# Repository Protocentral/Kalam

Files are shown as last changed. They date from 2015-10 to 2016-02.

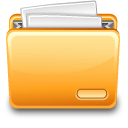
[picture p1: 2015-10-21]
Firmware/nodemcu-flasher-master/Resources/Images/File.png

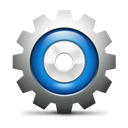
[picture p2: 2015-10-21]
Firmware/nodemcu-flasher-master/Resources/Images/Setting.png

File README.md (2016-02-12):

ProtoCentral Kalam IoT
======================
 [Kalam IoT  
 *ProtoCentral Kalam IoT (PC-4356)*](https://www.protocentral.com/iot/935-kalam-out-of-box-iot.html?search_query=kalam&results=1)

 Internet of Things or IOT is the new hot chic in the market. People seek to connect everything, from their pets to their garage doors to the Internet. The power of connected devices helps one to control it from anywhere in the world. On the other hand, Makers out there are seeking a platform that is easier to use, less cumbersome and more importantly easy on their pockets. With so many platforms out there based on the popular ESP8266, an extremely low cost WiFi module, it is indeed getting difficult for one to choose the right platform. Most commercially available modules are in the form of breakout boards. These require you to work with the limited I/O pins and more importantly will require an additional Arduino board or flashing the ESP8266 core. This can make life miserable for most makers. 

 To make it easier for developers and users alike we made a new genre of IoT platform called the OOB IoT (Out of the Box IoT)! Kalam V1 is an OOB IoT platform. It is an easy to use Arduino based platform that has an integrated ESP8266 module. Just open the box and get started on your projects without having to configure a breakout borad to work with an Arduino! 
This tiny inexpensive hulk of an IoT module in its first avatar (Kalam V1) comes as a single board with power support through USB or an external source through the RAW pin. In the second version we will introduce support for battery packs (and include a couple of battery packs) that can make your life easier as a developer/maker.

 We love our scientists and to commemorate one of the greatest scientists who also served as the most ebullient presidents of India, we aptly named our product Kalam after the late Dr. A.P.J Abdul Kalam. He chose to show the path to millions of students in India and abroad. Kindled their imaginations with his oratory skills and his writings. On occasion of his birthday we present this great platform, we hope will give the IoT space the necessary fillip. 
Inline with Make in India initiatives this is one of our first products of many we will develop, that will help makers and creators across the world!

Features Overload!
-------------------
*	Slide switch - Serial communication support to work on ESP or Atmega328 module individually
*	Firmware upgrade for ESP through USB
*	On board FTDI
*	Onboard regulator 3.3v with 800mA (with a max input of 6V)
*	Can be powered on/off using USB or external supply 
*	Board is pre-flashed  with an AT command set firmware and the same can be used to control ESP8266 module
*	Extra ESP8266 pins broken out for any additional usage requirements
*	802.11 b/g/n
*	Wi-Fi Direct (P2P), soft-AP
*	Integrated TCP/IP protocol stack

Includes:
----------
* Kalam with headers
* Micro USB type-B cable 

Repository Contents
-------------------
* **/Firmware**  - Firmware and bin files for ESP8266
* **/Libraries** - Arduino library and example sketches.
* **/Hardware**  - All Eagle design files (.brd, .sch)

License Information
-------------------
This product is open source!

Please use, reuse, and modify these files as you see fit. Please maintain attribution to Protocentral and release anything derivative under the same license.

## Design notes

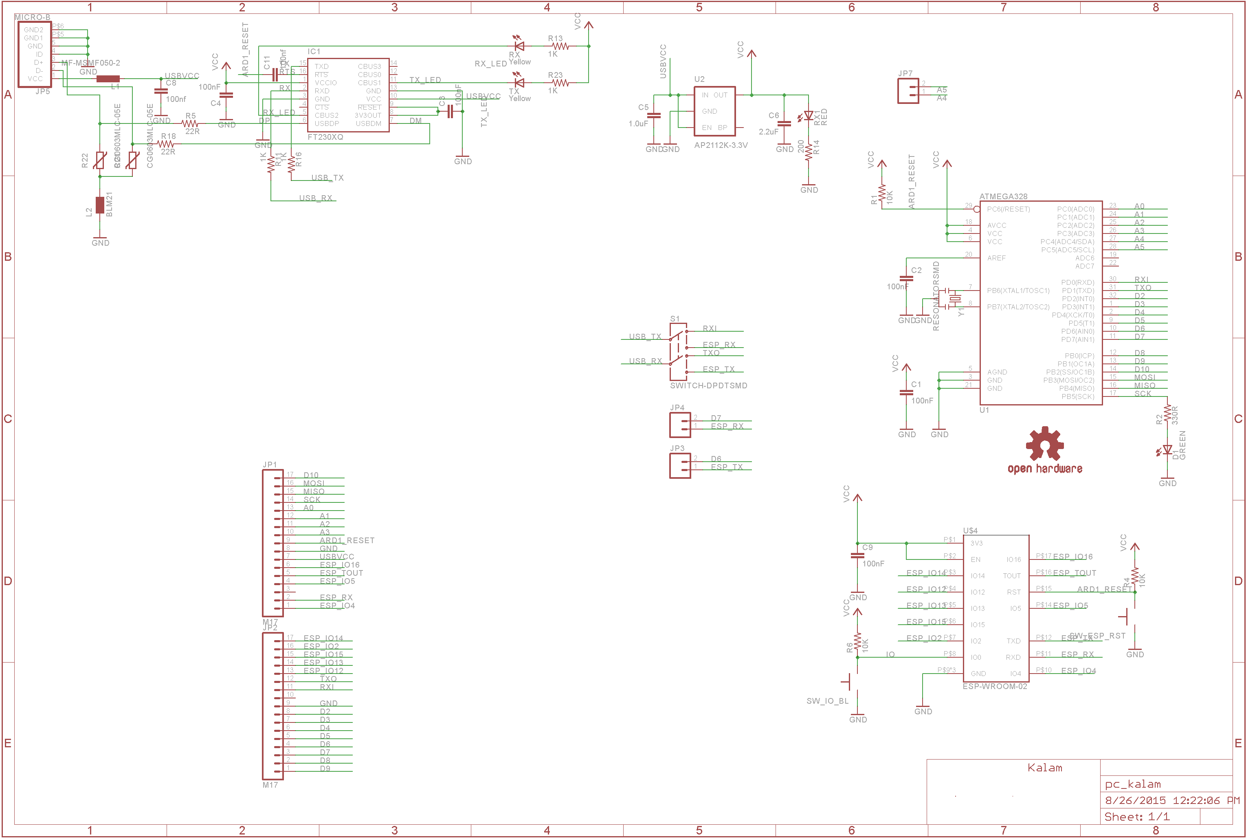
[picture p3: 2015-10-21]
Hardware/Kalam/Kalam.png

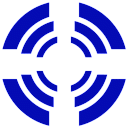
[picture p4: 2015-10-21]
Firmware/nodemcu-flasher-master/Resources/Images/Wait.GIF

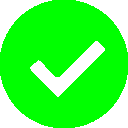
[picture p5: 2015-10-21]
Firmware/nodemcu-flasher-master/Resources/Images/Yes.png

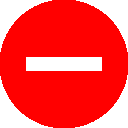
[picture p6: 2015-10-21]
Firmware/nodemcu-flasher-master/Resources/Images/No.png

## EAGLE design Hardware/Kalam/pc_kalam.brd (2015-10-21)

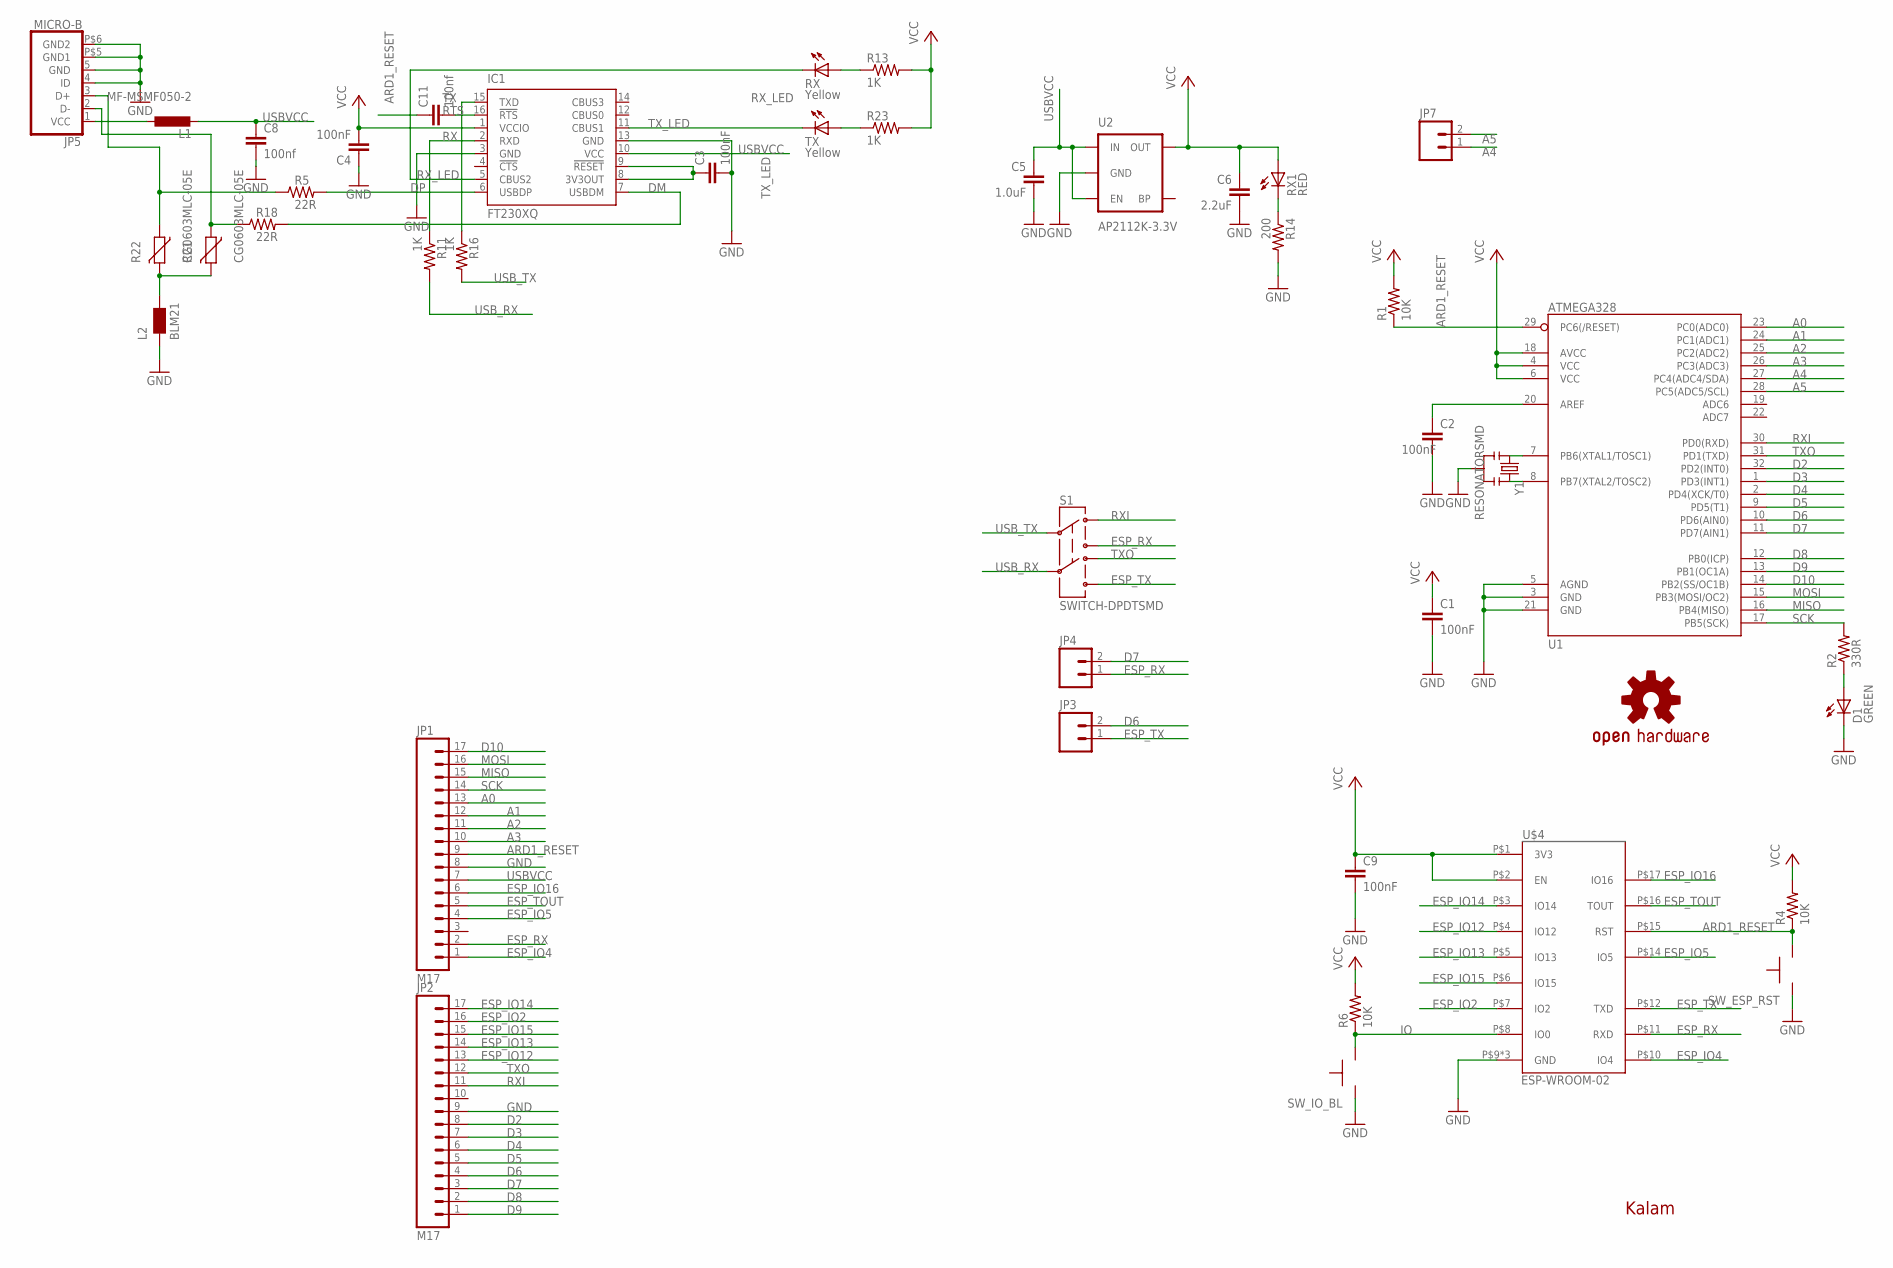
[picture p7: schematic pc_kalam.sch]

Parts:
C1, C2, C9: 100nF; C0402
C3, C4: 100nF; C0805
C5: 1.0uF; 0805
C6: 2.2uF; C0805
C8, C11: 100nf; C0805
D1: GREEN; LED-0603
IC1: FT230XQ; QFN16
JP1, JP2: M17; 1X17
JP3, JP4, JP7: M02PTH; 1X02
JP5: MICRO-B
L1: MF-MSMF050-2; L1812
L2: BLM21; 0805
R1, R4, R6: 10K; R0402
R2: 330R; R0402
R5, R18: 22R; R0805
R11, R13, R16, R23: 1K; R0805
R14: 200; R0805
R21, R22: CG0603MLC-05E; CT/CN0603
RX: Yellow; CHIPLED_0603
RX1: RED; CHIPLED_0603
S1: SWITCH-DPDTSMD; AYZ0202
SW_ESP_RST: B3U-1000P
SW_IO_BL: B3U-1000P
TX: Yellow; CHIPLED_0603
U1: ATMEGA328; TQFP32-08
U2: AP2112K-3.3V; SOT23-5
U$1: OSHW-LOGOS; OSHW-LOGO-S
U$2, U$3: PROTY-LOGO; LOGO-PROTY
U$4: ESP-WROOM-02
U$5: KALAM
Y1: RESONATORSMD; RESONATOR-SMD

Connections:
A0: JP1.13, U1.23 (PC0(ADC0))
A1: JP1.12, U1.24 (PC1(ADC1))
A2: JP1.11, U1.25 (PC2(ADC2))
A3: JP1.10, U1.26 (PC3(ADC3))
A4: JP7.1, U1.27 (PC4(ADC4/SDA))
A5: JP7.2, U1.28 (PC5(ADC5/SCL))
ARD1_RESET: C11.1, JP1.9, R1.1, R4.1, SW_ESP_RST.P$2, U1.29 (PC6(/RESET)), U$4.P$15 (RST)
D2: JP2.8, U1.32 (PD2(INT0))
D3: JP2.7, U1.1 (PD3(INT1))
D4: JP2.6, U1.2 (PD4(XCK/T0))
D5: JP2.5, U1.9 (PD5(T1))
D6: JP2.4, JP3.2, U1.10 (PD6(AIN0))
D7: JP2.3, JP4.2, U1.11 (PD7(AIN1))
D8: JP2.2, U1.12 (PB0(ICP))
D9: JP2.1, U1.13 (PB1(OC1A))
D10: JP1.17, U1.14 (PB2(SS/OC1B))
DM: IC1.7 (USBDM), R18.2
DP: IC1.6 (USBDP), R5.2
ESP_IO2: JP2.16, U$4.P$7 (IO2)
ESP_IO4: JP1.1, U$4.P$10 (IO4)
ESP_IO5: JP1.4, U$4.P$14 (IO5)
ESP_IO12: JP2.13, U$4.P$4 (IO12)
ESP_IO13: JP2.14, U$4.P$5 (IO13)
ESP_IO14: JP2.17, U$4.P$3 (IO14)
ESP_IO15: JP2.15, U$4.P$6 (IO15)
ESP_IO16: JP1.6, U$4.P$17 (IO16)
ESP_RX: JP1.2, JP4.1, S1.3, U$4.P$11 (RXD)
ESP_TOUT: JP1.5, U$4.P$16 (TOUT)
ESP_TX: JP3.1, S1.6, U$4.P$12 (TXD)
GND: C1.2, C2.2, C3.2, C4.1, C5.2, C6.2, C8.2, C9.2, D1.C, IC1.3 (GND), IC1.13 (GND), JP1.8, JP2.9, JP5.4 (ID), JP5.5 (GND), JP5.P$5 (GND1), JP5.P$6 (GND2), L2.1, R14.2, SW_ESP_RST.P$1, SW_IO_BL.P$1, U1.3 (GND), U1.5 (AGND), U1.21 (GND), U2.2 (GND), U$4.P$9 (GND), U$4.P$13 (GND), U$4.P$18 (GND), Y1.2
IO: R6.1, SW_IO_BL.P$2, U$4.P$8 (IO0)
MISO: JP1.15, U1.16 (PB4(MISO))
MOSI: JP1.16, U1.15 (PB3(MOSI/OC2))
unnamed: C2.1, U1.20 (AREF)
unnamed: U1.8 (PB7(XTAL2/TOSC2)), Y1.3
unnamed: U1.7 (PB6(XTAL1/TOSC1)), Y1.1
unnamed: C3.1, IC1.8 (3V3OUT), IC1.9 (!RESET)
unnamed: R14.1, RX1.C
unnamed: D1.A, R2.1
unnamed: JP5.2 (D-), R18.1, R21.1
unnamed: JP5.1 (VCC), L1.1
unnamed: R13.1, RX.A
unnamed: R23.1, TX.A
unnamed: L2.2, R21.2, R22.2
unnamed: JP5.3 (D+), R5.1, R22.1
RTS: C11.2, IC1.16 (!RTS)
RX: IC1.2 (RXD), R11.1
RXI: JP2.11, S1.1, U1.30 (PD0(RXD))
RX_LED: IC1.5 (CBUS2), RX.C
SCK: JP1.14, R2.2, U1.17 (PB5(SCK))
TX: IC1.15 (TXD), R16.1
TXO: JP2.12, S1.4, U1.31 (PD1(TXD))
TX_LED: IC1.11 (CBUS1), TX.C
USBVCC: C5.1, C8.1, IC1.10 (VCC), JP1.7, L1.2, U2.1 (IN), U2.3 (EN)
USB_RX: R11.2, S1.5
USB_TX: R16.2, S1.2
VCC: C1.1, C4.2, C6.1, C9.1, IC1.1 (VCCIO), R1.2, R4.2, R6.2, R13.2, R23.2, RX1.A, U1.4 (VCC), U1.6 (VCC), U1.18 (AVCC), U2.5 (OUT), U$4.P$1 (3V3), U$4.P$2 (EN)

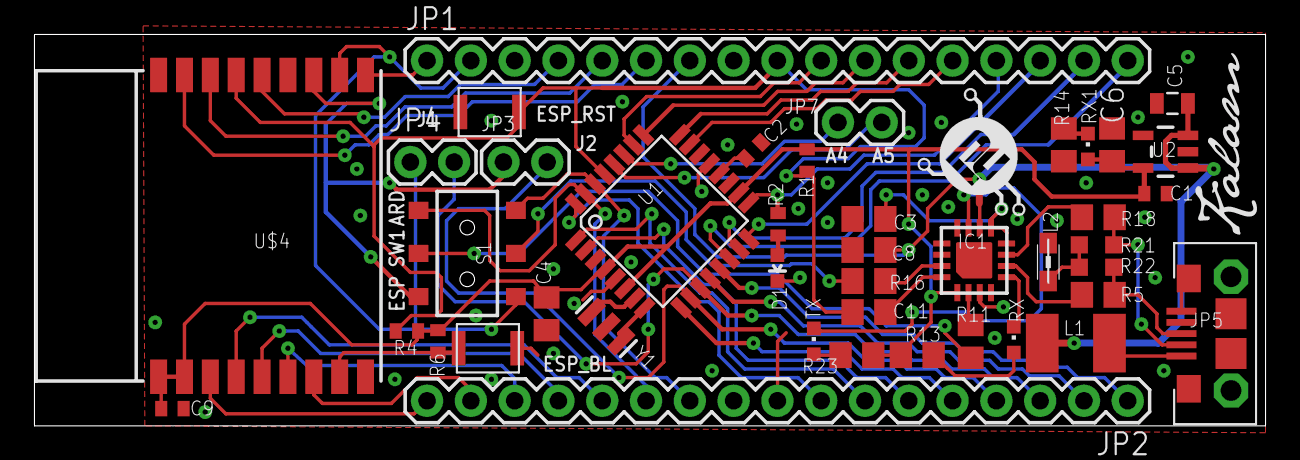
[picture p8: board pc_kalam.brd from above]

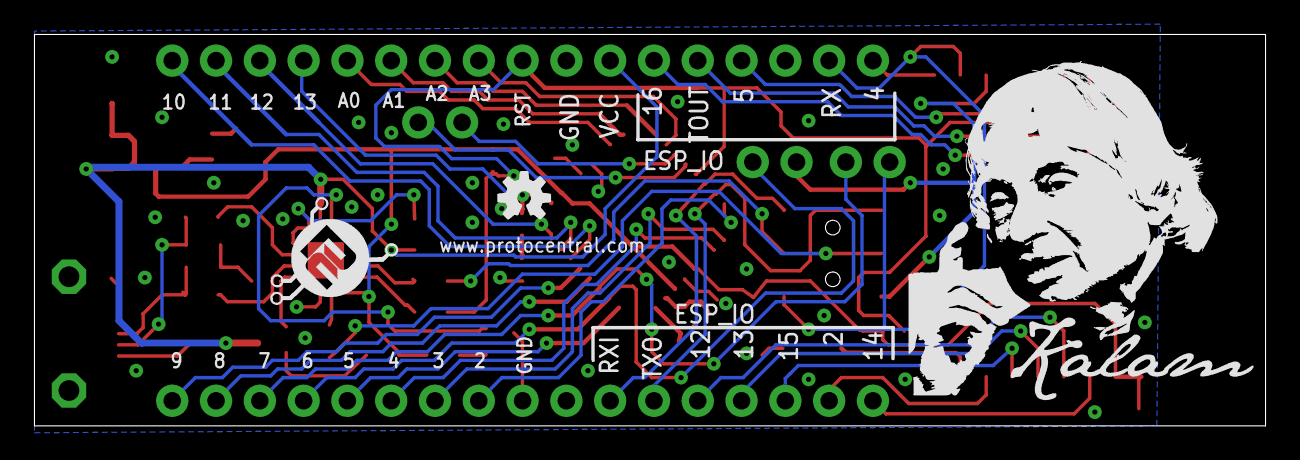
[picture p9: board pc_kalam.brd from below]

Board: 4 copper layers, 71.4 x 22.7 mm, 47 parts (3 on the bottom side), 57 nets.

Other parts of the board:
U$6: KALAM-NAME-ONLY

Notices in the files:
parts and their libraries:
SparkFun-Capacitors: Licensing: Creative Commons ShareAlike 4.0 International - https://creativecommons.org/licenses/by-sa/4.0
